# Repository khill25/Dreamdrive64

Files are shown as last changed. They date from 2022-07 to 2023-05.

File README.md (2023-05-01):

# DREAMDrive64
Nintendo 64 flash cart based around Raspberry Pi RP2040s. Load roms up to 64MB, EEPROM save support, supports all cic versions.

---
# Getting one
## Buy one from my website! 
https://dreamcraftindustries.com/products/dreamdrive64

## Build your own with PCBWay
You can load up the hw files in Kicad and use the PCBWay plugin. The PCBWay plugin will take you right to the PCBWay website with the gerbers loaded up and ready to order. 

### N64 Cartridge Shell
You can use a doner shell or find some on Aliexpress/Ebay.
The shell will need to be cut to accomodate the SD Card slot and USB port.

* SD Card Slot Cuts 
	* These cuts should be 15mm wide
		* This cut should start approximately 46.5mm from the bottom of the shell on the outside edge.
	* 3mm Deep on the back shell
	* Less than 1mm deep on the front shell
	
* "Boot" Button (Press while plugging in USB to load new firmware)
	* Drill small hole
		* 28.6mm from left side of back shell (5mm right of screw hole)
		* ~6.2mm down from the screw hole

---
# Current Dev Status
* DREAMDrive64 can boot roms and has made the v1.0.0 release! 
	* Menu rom can navigate the sd file system assuming a rational number of files/folders (256 at the moment per directory, 10 directory depth limit)
	* Menu rom can render thumbnail boxart of a rom when scrolling through file list
	* Libdragon changes are needed if you want to compile your own rom for the firmware, those changes are in PR over at the libdragon repo
	* Firmware is stable with a v1.0.0 release available right now, with more improvements on the way.

## Features
| Feature					| Status 	 | Notes 	|
|---:|:---|---:|
| Rom Loading				| Complete!	 |			|
| SD Filesystem navigation	| Complete!	 | Folder/File limit ~100 per directory 		|
| Wifi						| Soon		 |			|
| EEPROM save support		| Complete!		 |			|
| SRAM support 				| Complete!  | Some games require much higher sram timing than is currently working. SRAM doesn't save to SD card. SRAM data will only persist while the game is running.		|
| CIC Compatibility			| Complete!	 | All cic versions should work. Country version however needs to be matched with the version flashed to the board (PAL vs NTSC) |

**ROM Compatibility **
Still working towards booting at full sdk speeds (0x1240) but current v1.0.0 firmware is at 0x2040. SRAM access isn't fast enough for some titles. 

# Command Registers
| Register					| Address 	 | Length 	| Notes 				|
|---:|:---|:---|---:|
| Base Address				| 0x1FFE0000 | 0x1000	| 4kB buffer/Currently shared as internal buffer 			| v1/lite and v2|
| Command Interface Start	| 0x1FFE1000 | 0x0800	|						| 
| Random Seed 			| 0x1FFE0008 | 0x4		|						| 
| Start SD Read				| 0x1FFE000C | 0x4		|						| 
| SD Rom Select				| 0x1FFE0010 | 0x4		| Loads selected rom into psram	|
| SD Busy					| 0x1FFE0014 | 0x4  	| After an sd request is sent, data will be available at `Base Address` once sd busy = 0						| v2	|
| SD Read Sector Register 0	| 0x1FFE0018 | 0x4		| High bits of uint64 sector to read	|
| SD Read Sector Register 1	| 0x1FFE001C | 0x4		| Low bits of uin64 sector to read	|
| SD Read number of sectors	| 0x1FFE0020 | 0x4		| v2 code has this hard coded to always read 1 sector	|
| Select Rom				| 0x1FFE0024 | 0xFF		| Send title of rom to load from sd card e.g. "my_homebrew_rom.z64"	|

# Examples of SD card access
There is an open PR for sdfs support in the Libdragon repo! Check that out if you want to patch your libdragon installs.

Libdragon sdfs implementation for DreamDrive64. This code is just snippets and may not "just work" yet. It should give you an idea of how to use the command registers and the order that things need to be done in.
Example code to load a rom with the file's name. Updates to Libdragon's `debug.c` must be made if you plan on using file methods (e.g. f_open, f_read, etc...)
```
// From command register table above
// PC64_CIBASE_ADDRESS_START = "Command Interface start"
// PC64_REGISTER_SD_SELECT_ROM = "Select Rom"
void loadRomAtSelection(char* selectedFile) {
    char* fileToLoad = malloc(sizeof(char*) * 256);
    sprintf(fileToLoad, "%s", selectedFile);

    // Write the file name to the cart buffer
    uint32_t len_aligned32 = (strlen(fileToLoad) + 3) & (-4);
    data_cache_hit_writeback_invalidate(fileToLoad, len_aligned32);
    pi_write_raw(fileToLoad, PC64_BASE_ADDRESS_START, 0, len_aligned32);

    uint32_t sdSelectRomFilenameLength = strlen(fileToLoad);
    io_write(PC64_CIBASE_ADDRESS_START + PC64_REGISTER_SD_SELECT_ROM, sdSelectRomFilenameLength);

    wait_ms(100);
}
```

## Wait for SD
Taken from current (unmerged) libdragon implementation patch
```
static uint8_t pc64_sd_wait() {
    uint32_t timeout = 0;
    uint32_t isBusy __attribute__((aligned(8)));
	isBusy = 1;

    // Wait until the cartridge interface is ready
    do {
		
        // returns 1 while sd card is busy
		isBusy = io_read(PC64_CIBASE_ADDRESS_START + PC64_REGISTER_SD_BUSY);
        
        // Took too long, abort
        if((timeout++) > 10000000) {
			fprintf(stdout, "SD_WAIT timed out. isBusy: %ld\n", isBusy);
			return -1;
		}
    }
    while(isBusy != 0);
    (void) timeout; // Needed to stop unused variable warning

    // Success
    return 0;
}
```

## Read
Taken from current (unmerged) libdragon implementation patch
```
static DRESULT fat_disk_read_pc64(BYTE* buff, LBA_t sector, UINT count) {
	_Static_assert(FF_MIN_SS == 512, "this function assumes sector size == 512");
	_Static_assert(FF_MAX_SS == 512, "this function assumes sector size == 512");

	int retryCount = 2;
	int i = 0;
	do {
		uint64_t current_sector = sector + i;
		
		uint32_t part0 __attribute__((aligned(8)));
		part0 = (current_sector & 0xFFFFFFFF00000000LL) >> 32;

		uint32_t part1 __attribute__((aligned(8)));
		part1 = (current_sector & 0x00000000FFFFFFFFLL);

		// send sector
		io_write(PC64_CIBASE_ADDRESS_START + PC64_REGISTER_SD_READ_SECTOR0, part0);

		io_write(PC64_CIBASE_ADDRESS_START + PC64_REGISTER_SD_READ_SECTOR1, part1);

		// send num sectors to read
		io_write(PC64_CIBASE_ADDRESS_START + PC64_REGISTER_SD_READ_NUM_SECTORS, 1);

		// start the load
		io_write(PC64_CIBASE_ADDRESS_START + PC64_COMMAND_SD_READ, 1);

        // wait for the sd card to finish
        if(pc64_sd_wait() == 0) {
			data_cache_hit_writeback_invalidate(buff, 512);
			dma_read(buff, PC64_BASE_ADDRESS_START, 512);
			buff += 512;
			i++;
		} else {
			retryCount--;
			fprintf(stderr, "wait timeout\n");
		}

		if (retryCount <= 0) {
			break;
		}
		
	} while (i < count);

	return RES_OK;
}
```

## Write
Not supported yet!

# Join in on the fun!
Dreamcraft Industries discord

[Join the Dreamcraft Discord!](https://discord.gg/yawWMcv6tC)

Original PicoCart64 discord
Join the Discord server to participate in the discussion and development of this project.
[Dubious Technology Discord](https://discord.gg/2Gb3jWqqja)

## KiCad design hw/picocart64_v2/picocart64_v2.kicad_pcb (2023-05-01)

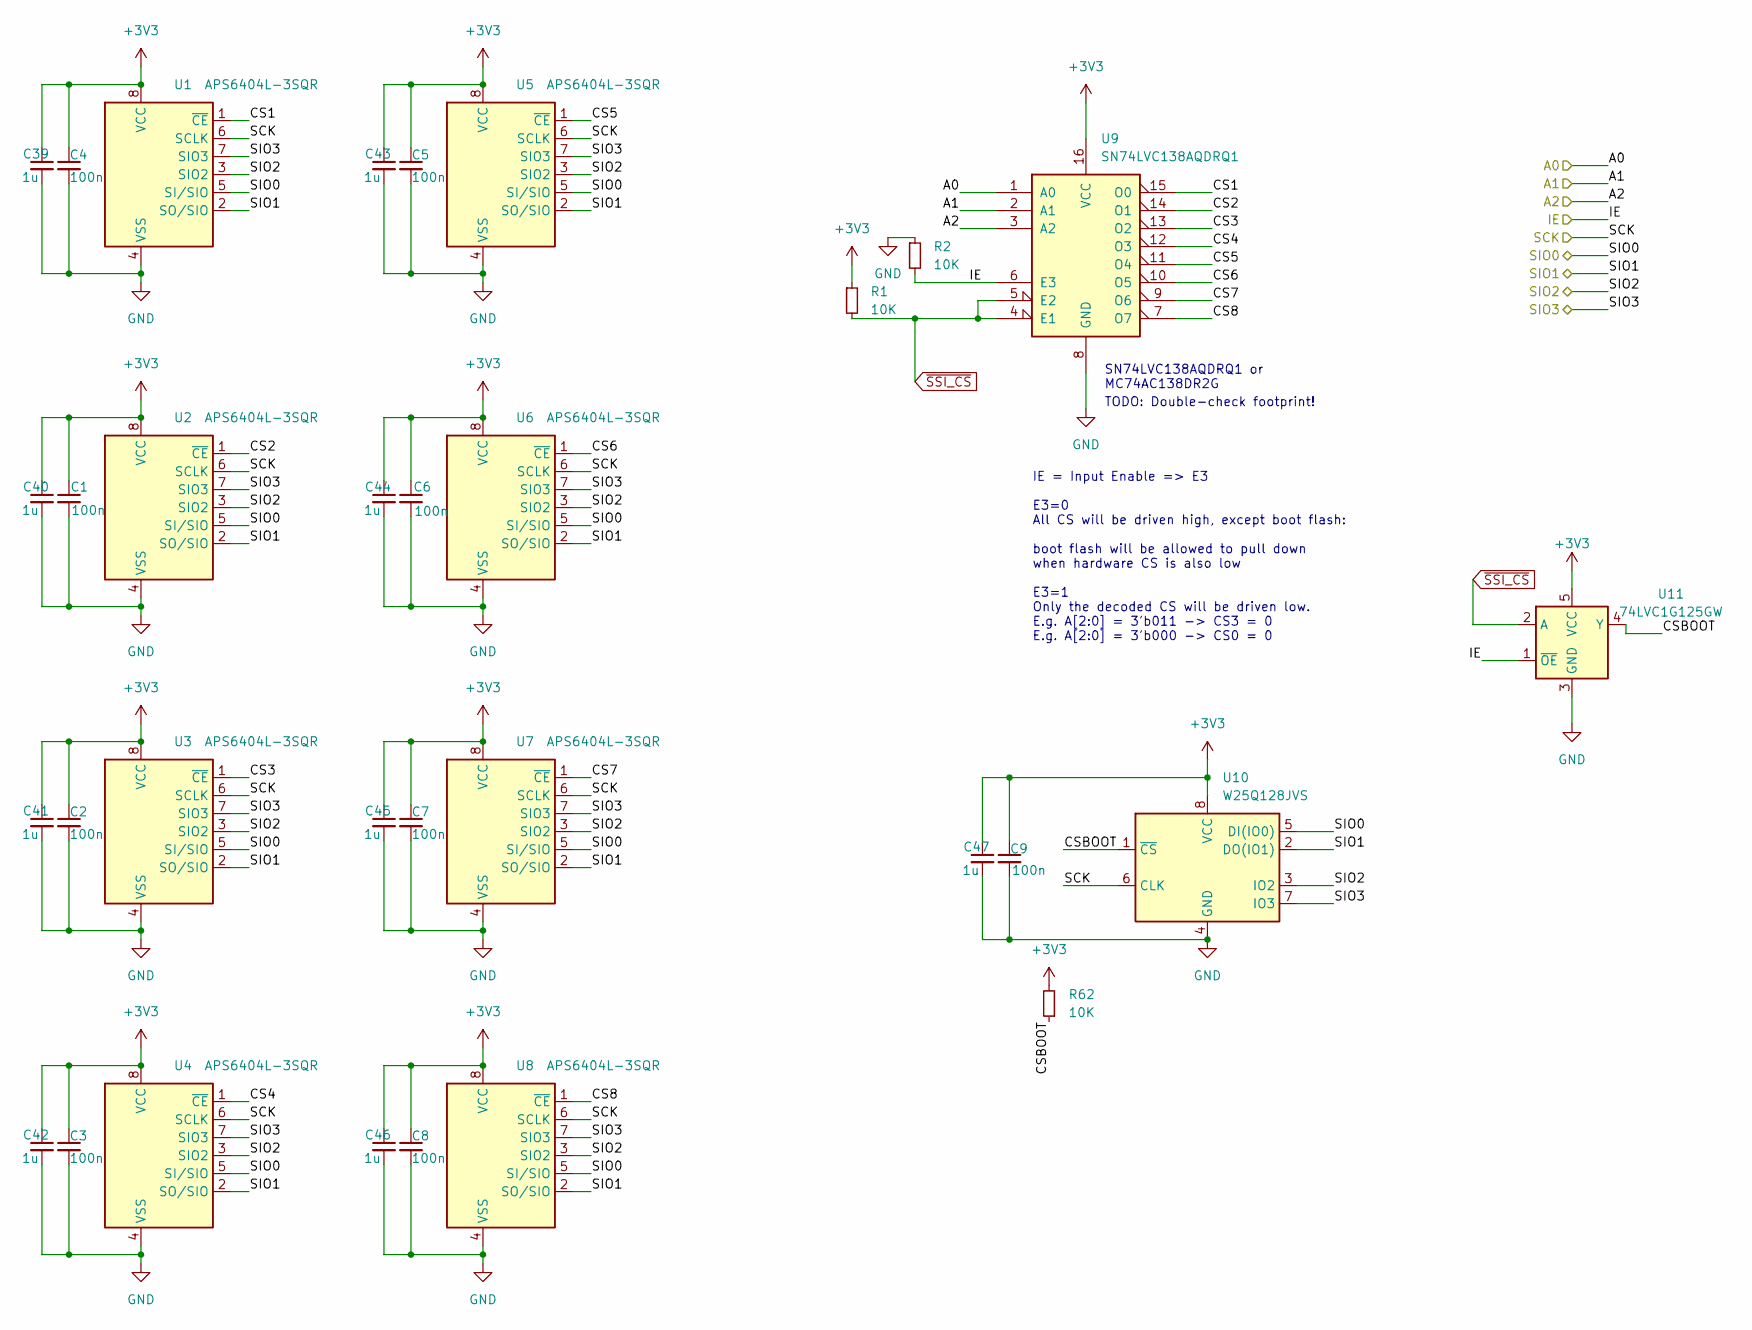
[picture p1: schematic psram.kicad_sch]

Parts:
C1, C2, C3, C4, C5, C6, C7, C8, C9: 100n; C_0402_1005Metric; LCSC C1525
C39, C40, C41, C42, C43, C44, C45, C46, C47: 1u; C_0402_1005Metric; LCSC C14445
R1, R2, R62: 10K; R_0402_1005Metric; LCSC C406733
U1, U2, U3, U4, U5, U6, U7, U8: APS6404L-3SQR; SOP-8_3.76x4.96mm_P1.27mm; LCSC Mouser: APS6404L-3SQR-SN
U9: SN74LVC138AQDRQ1; SOP-16_4.4x10.4mm_P1.27mm; LCSC C7816
U10: W25Q128JVS; SOIC-8_5.23x5.23mm_P1.27mm; LCSC C97521
U11: 74LVC1G125GW; SOT-353_SC-70-5; LCSC C12519

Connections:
+3V3: C1.1, C2.1, C3.1, C4.1, C5.1, C6.1, C7.1, C8.1, C9.1, C39.1, C40.1, C41.1, C42.1, C43.1, C44.1, C45.1, C46.1, C47.1, R1.1, R62.2, U1.8 (VCC), U2.8 (VCC), U3.8 (VCC), U4.8 (VCC), U5.8 (VCC), U6.8 (VCC), U7.8 (VCC), U8.8 (VCC), U9.16 (VCC), U10.8 (VCC), U11.5 (VCC); also elsewhere on the board
/Mainboard/DEMUX_A0: U9.1 (A0); also elsewhere on the board
/Mainboard/DEMUX_A1: U9.2 (A1); also elsewhere on the board
/Mainboard/DEMUX_A2: U9.3 (A2); also elsewhere on the board
/Mainboard/DEMUX_IE: R2.2, U9.6 (E3), U11.1 (~OE); also elsewhere on the board
/Mainboard/SSI_SCLK: U1.6 (SCLK), U2.6 (SCLK), U3.6 (SCLK), U4.6 (SCLK), U5.6 (SCLK), U6.6 (SCLK), U7.6 (SCLK), U8.6 (SCLK), U10.6 (CLK); also elsewhere on the board
/Mainboard/SSI_SD0: U1.5 (SI/SIO), U2.5 (SI/SIO), U3.5 (SI/SIO), U4.5 (SI/SIO), U5.5 (SI/SIO), U6.5 (SI/SIO), U7.5 (SI/SIO), U8.5 (SI/SIO), U10.5 (DI(IO0)); also elsewhere on the board
/Mainboard/SSI_SD1: U1.2 (SO/SIO), U2.2 (SO/SIO), U3.2 (SO/SIO), U4.2 (SO/SIO), U5.2 (SO/SIO), U6.2 (SO/SIO), U7.2 (SO/SIO), U8.2 (SO/SIO), U10.2 (DO(IO1)); also elsewhere on the board
/Mainboard/SSI_SD2: U1.3 (SIO2), U2.3 (SIO2), U3.3 (SIO2), U4.3 (SIO2), U5.3 (SIO2), U6.3 (SIO2), U7.3 (SIO2), U8.3 (SIO2), U10.3 (IO2); also elsewhere on the board
/Mainboard/SSI_SD3: U1.7 (SIO3), U2.7 (SIO3), U3.7 (SIO3), U4.7 (SIO3), U5.7 (SIO3), U6.7 (SIO3), U7.7 (SIO3), U8.7 (SIO3), U10.7 (IO3); also elsewhere on the board
/PSRAM Array/CS1: U1.1 (~CE), U9.15 (O0)
/PSRAM Array/CS2: U2.1 (~CE), U9.14 (O1)
/PSRAM Array/CS3: U3.1 (~CE), U9.13 (O2)
/PSRAM Array/CS4: U4.1 (~CE), U9.12 (O3)
/PSRAM Array/CS5: U5.1 (~CE), U9.11 (O4)
/PSRAM Array/CS6: U6.1 (~CE), U9.10 (O5)
/PSRAM Array/CS7: U7.1 (~CE), U9.9 (O6)
/PSRAM Array/CS8: U8.1 (~CE), U9.7 (O7)
/PSRAM Array/CSBOOT: R62.1, U10.1 (~CS), U11.4 (Y)
GND: C1.2, C2.2, C3.2, C4.2, C5.2, C6.2, C7.2, C8.2, C9.2, C39.2, C40.2, C41.2, C42.2, C43.2, C44.2, C45.2, C46.2, C47.2, R2.1, U1.4 (VSS), U2.4 (VSS), U3.4 (VSS), U4.4 (VSS), U5.4 (VSS), U6.4 (VSS), U7.4 (VSS), U8.4 (VSS), U9.8 (GND), U10.4 (GND), U11.3 (GND); also elsewhere on the board
~SSI_CS: R1.2, U9.4 (E1), U9.5 (E2), U11.2 (A); also elsewhere on the board

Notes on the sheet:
TODO: Double-check footprint!
IE = Input Enable => E3 E3=0 All CS will be driven high, except boot flash: boot flash will be allowed to pull down when hardware CS is also low E3=1 Only the decoded CS will be driven low. E.g. A[2:0] = 3'b011 -> CS3 = 0 E.g. A[2:0] = 3'b000 -> CS0 = 0
SN74LVC138AQDRQ1 or MC74AC138DR2G

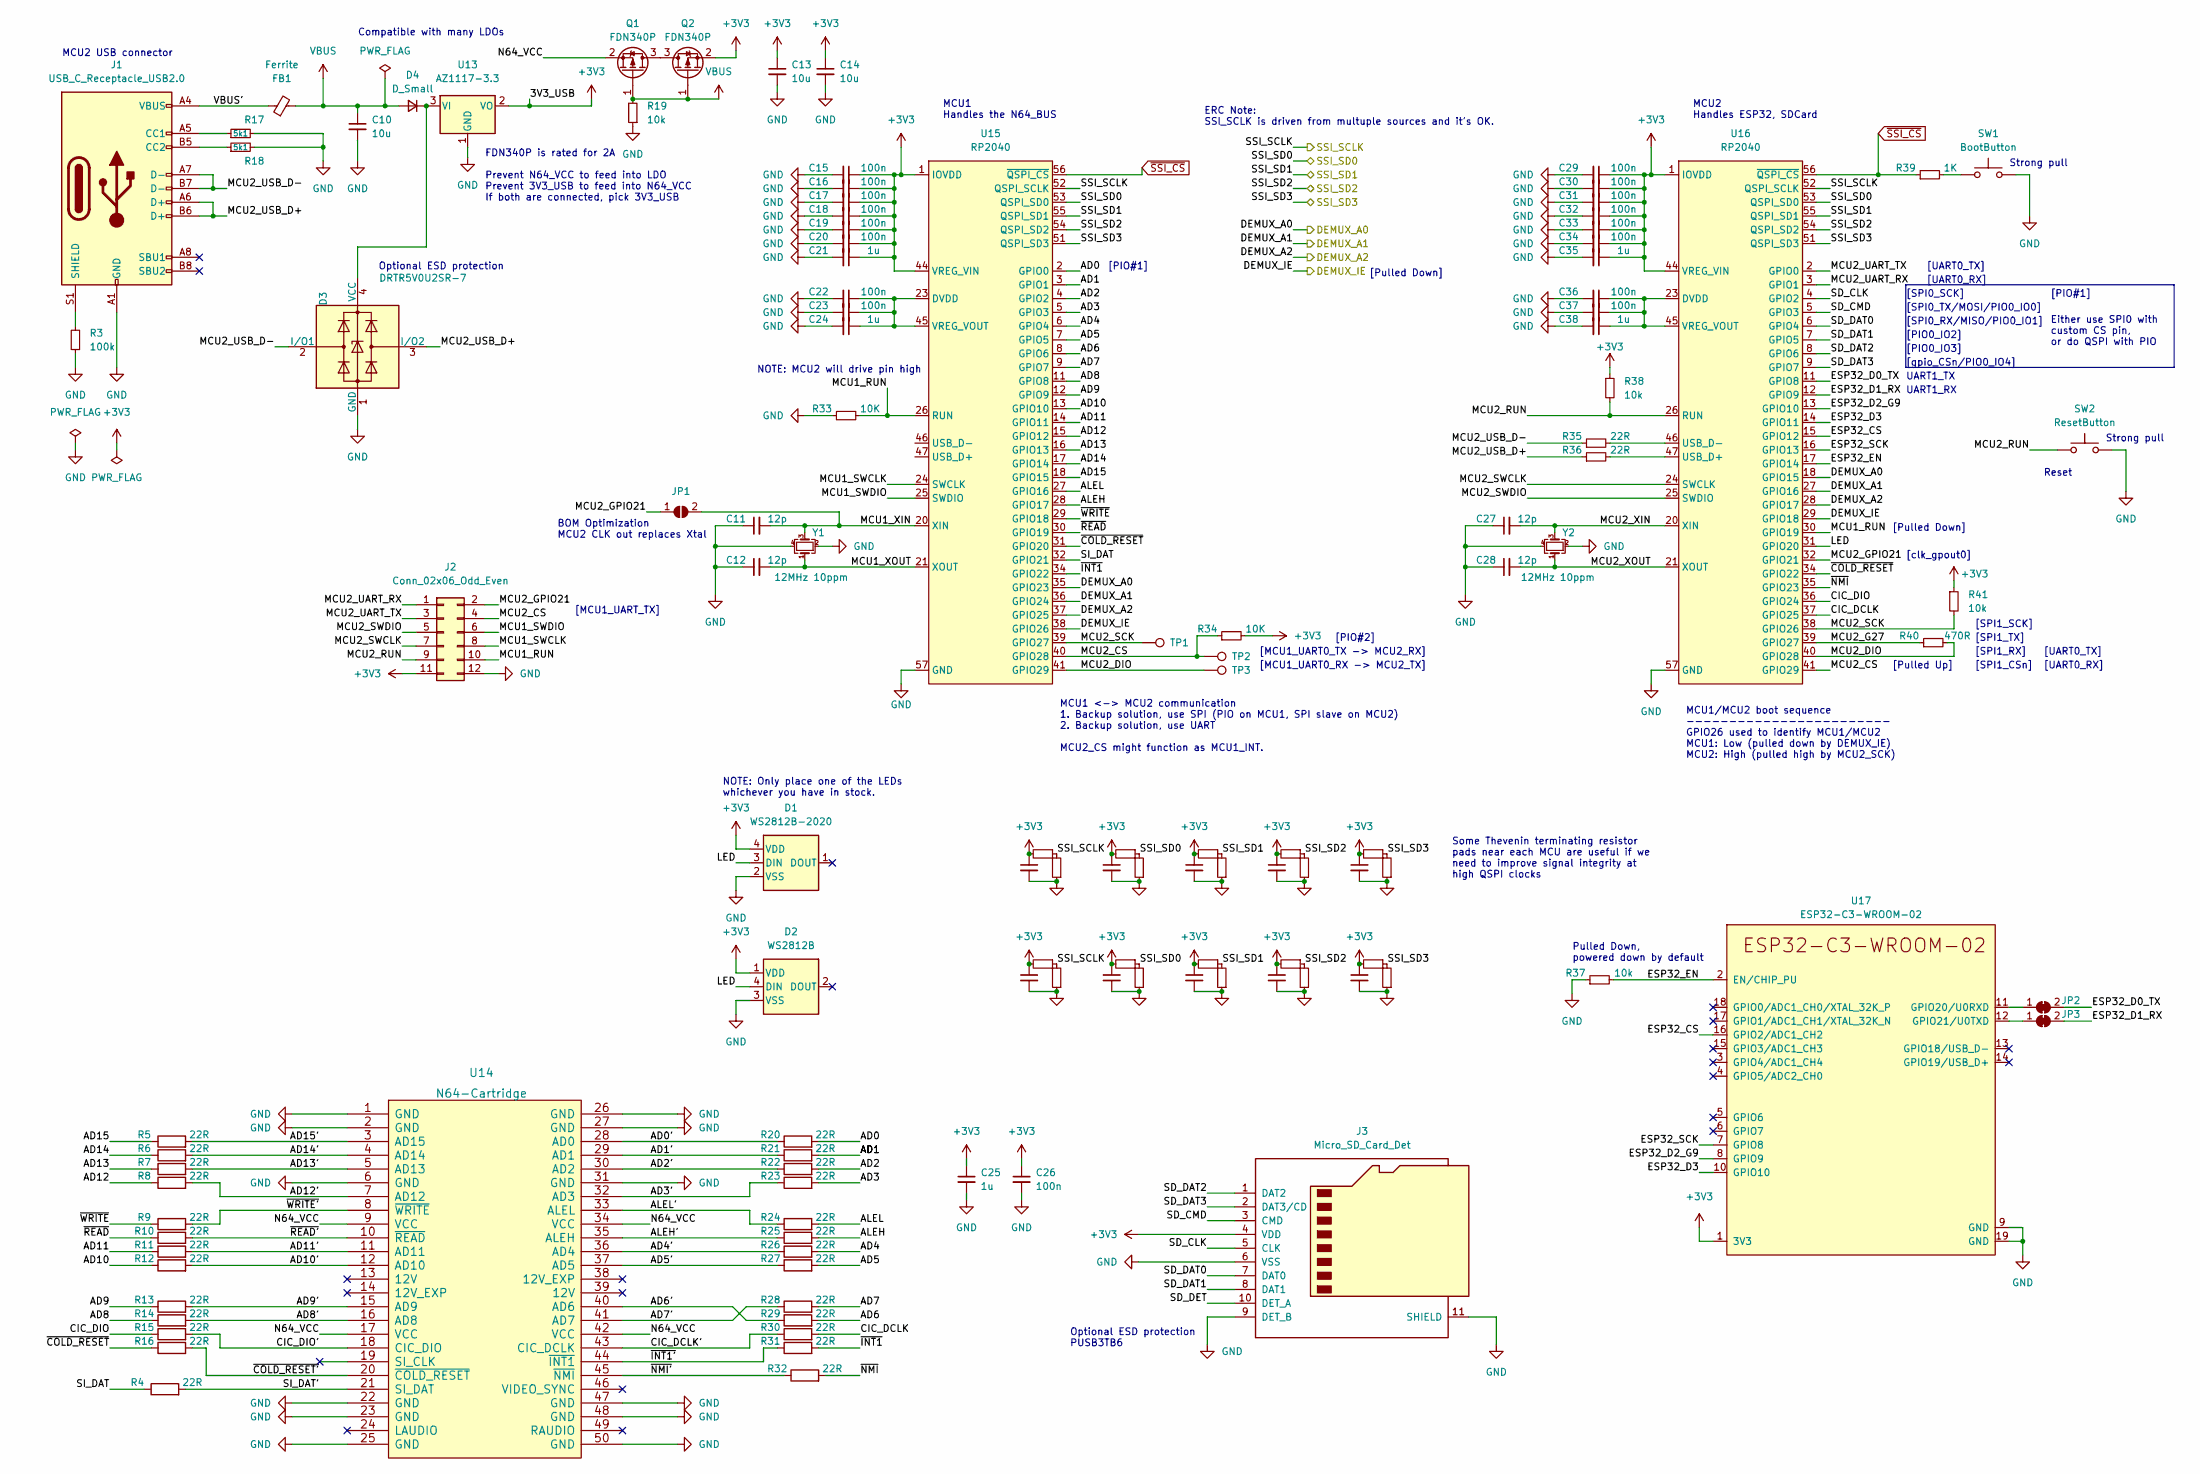
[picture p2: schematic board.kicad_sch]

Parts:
C10, C13, C14: 10u; C_0603_1608Metric; LCSC C15525
C11, C12, C27, C28: 12p; C_0402_1005Metric; LCSC C106201
C15, C16, C17, C18, C19, C20, C22, C23, C26, C29, C30, C31, C32, C33, C34, C36, C37, C48, C49, C50, C51, C52, C53, C54, C55, C56, C57: 100n; C_0402_1005Metric; LCSC C1525
C21, C24, C25, C35, C38: 1u; C_0402_1005Metric; LCSC C14445
D1: WS2812B-2020; LCSC C965555
D2: WS2812B; LED_WS2812B_PLCC4_5.0x5.0mm_P3.2mm; LCSC C114586
D3: DRTR5V0U2SR-7; SOT-143; LCSC C443828
D4: D_Small; D_SMA; LCSC C22452
FB1: Ferrite; L_0603_1608Metric; LCSC C76892
J1: USB_C_Receptacle_USB2.0; USB_C_Receptacle_GT-USB-7010; LCSC C136423
J2: Conn_02x06_Odd_Even; PinHeader_2x06_P2.54mm_Vertical_SMD
J3: Micro_SD_Card_Det; microSD_HC_Molex_104031-0811; LCSC C585350
JP1: SolderJumper_2_Open; SolderJumper-2_Small_Open
JP2, JP3: SolderJumper_2_Bridged; SolderJumper-2_Small_Closed
Q1, Q2: FDN340P; SOT-23; LCSC C347510
R3: 100k; R_0402_1005Metric; LCSC C25741
R4, R5, R6, R7, R8, R9, R10, R11, R12, R13, R14, R15, R16, R20, R21, R22, R23, R24, R25, R26, R27, R28, R29, R30, R31, R32, R35, R36: 22R; R_0402_1005Metric; LCSC C409710
R17, R18: 5k1; R_0402_1005Metric; LCSC C105873
R19, R37, R38, R41: 10k; R_0402_1005Metric; LCSC C406733
R33, R34: 10K; R_0402_1005Metric; LCSC C406733
R39, R42, R43, R44, R45, R46, R47, R48, R49, R50, R51, R52, R53, R54, R55, R56, R57, R58, R59, R60, R61: 1K; R_0402_1005Metric; LCSC C105637
R40: 470R; R_0402_1005Metric; LCSC C25117
SW1: BootButton; SW_SPST_FSMSM; LCSC C318938
SW2: ResetButton; SW_SPST_FSMSM; LCSC C318938
TP1: TP_MCU2_SCK; TestPoint_Pad_D1.0mm
TP2: TP_MCU2_CS; TestPoint_Pad_D1.0mm
TP3: TP_MCU2_DIO; TestPoint_Pad_D1.0mm
U13: AZ1117-3.3; SOT-223; LCSC C108495
U14: N64-Cartridge; N64-Connector
U15, U16: RP2040; QFN-56_EP_7x7_Pitch0.4mm; LCSC C2040
U17: ESP32-C3-WROOM-02; LCSC C2934560
Y1, Y2: 12MHz 10ppm; Crystal_SMD_2520-4Pin_2.5x2.0mm; LCSC C521567

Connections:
+3V3: C13.1, C14.1, C15.1, C16.1, C17.1, C18.1, C19.1, C20.1, C21.1, C25.1, C26.1, C29.1, C30.1, C31.1, C32.1, C33.1, C34.1, C35.1, C48.1, C49.1, C50.1, C51.1, C52.1, C53.1, C54.1, C55.1, C56.1, C57.1, D1.4 (VDD), D2.1 (VDD), J2.11, J3.4 (VDD), Q2.2 (S), R34.2, R38.1, R41.1, R42.2, R43.2, R46.2, R47.2, R50.2, R51.2, R54.2, R55.2, R58.2, R59.2, U13.2 (VO), U15.1 (IOVDD), U15.10 (IOVDD), U15.22 (IOVDD), U15.33 (IOVDD), U15.42 (IOVDD), U15.43 (ADC_AVDD), U15.44 (VREG_VIN), U15.48 (USB_VDD), U15.49 (IOVDD), U16.1 (IOVDD), U16.10 (IOVDD), U16.22 (IOVDD), U16.33 (IOVDD), U16.42 (IOVDD), U16.43 (ADC_AVDD), U16.44 (VREG_VIN), U16.48 (USB_VDD), U16.49 (IOVDD), U17.1 (3V3); also elsewhere on the board
/Mainboard/AD0: R20.2, U15.2 (GPIO0)
/Mainboard/AD0': R20.1, U14.28 (AD0)
/Mainboard/AD1: R21.2, U15.3 (GPIO1)
/Mainboard/AD1': R21.1, U14.29 (AD1)
/Mainboard/AD2: R22.2, U15.4 (GPIO2)
/Mainboard/AD2': R22.1, U14.30 (AD2)
/Mainboard/AD3: R23.2, U15.5 (GPIO3)
/Mainboard/AD3': R23.1, U14.32 (AD3)
/Mainboard/AD4: R26.2, U15.6 (GPIO4)
/Mainboard/AD4': R26.1, U14.36 (AD4)
/Mainboard/AD5: R27.2, U15.7 (GPIO5)
/Mainboard/AD5': R27.1, U14.37 (AD5)
/Mainboard/AD6: R29.2, U15.8 (GPIO6)
/Mainboard/AD6': R29.1, U14.40 (AD6)
/Mainboard/AD7: R28.2, U15.9 (GPIO7)
/Mainboard/AD7': R28.1, U14.41 (AD7)
/Mainboard/AD8: R14.1, U15.11 (GPIO8)
/Mainboard/AD8': R14.2, U14.16 (AD8)
/Mainboard/AD9: R13.1, U15.12 (GPIO9)
/Mainboard/AD9': R13.2, U14.15 (AD9)
/Mainboard/AD10: R12.1, U15.13 (GPIO10)
/Mainboard/AD10': R12.2, U14.12 (AD10)
/Mainboard/AD11: R11.1, U15.14 (GPIO11)
/Mainboard/AD11': R11.2, U14.11 (AD11)
/Mainboard/AD12: R8.1, U15.15 (GPIO12)
/Mainboard/AD12': R8.2, U14.7 (AD12)
/Mainboard/AD13: R7.1, U15.16 (GPIO13)
/Mainboard/AD13': R7.2, U14.5 (AD13)
/Mainboard/AD14: R6.1, U15.17 (GPIO14)
/Mainboard/AD14': R6.2, U14.4 (AD14)
/Mainboard/AD15: R5.1, U15.18 (GPIO15)
/Mainboard/AD15': R5.2, U14.3 (AD15)
/Mainboard/ALEH: R25.2, U15.28 (GPIO17)
/Mainboard/ALEH': R25.1, U14.35 (ALEH)
/Mainboard/ALEL: R24.2, U15.27 (GPIO16)
/Mainboard/ALEL': R24.1, U14.33 (ALEL)
/Mainboard/CIC_DCLK: R30.2, U16.37 (GPIO25)
/Mainboard/CIC_DCLK': R30.1, U14.43 (CIC_DCLK)
/Mainboard/CIC_DIO: R15.1, U16.36 (GPIO24)
/Mainboard/CIC_DIO': R15.2, U14.18 (CIC_DIO)
/Mainboard/DEMUX_A0: U15.35 (GPIO23), U16.18 (GPIO15); also elsewhere on the board
/Mainboard/DEMUX_A1: U15.36 (GPIO24), U16.27 (GPIO16); also elsewhere on the board
/Mainboard/DEMUX_A2: U15.37 (GPIO25), U16.28 (GPIO17); also elsewhere on the board
/Mainboard/DEMUX_IE: U15.38 (GPIO26), U16.29 (GPIO18); also elsewhere on the board
/Mainboard/ESP32_CS: U16.15 (GPIO12), U17.16 (GPIO2/ADC1_CH2)
/Mainboard/ESP32_D0_TX: JP2.2 (B), U16.11 (GPIO8)
/Mainboard/ESP32_D1_RX: JP3.2 (B), U16.12 (GPIO9)
/Mainboard/ESP32_D2_G9: U16.13 (GPIO10), U17.8 (GPIO9)
/Mainboard/ESP32_D3: U16.14 (GPIO11), U17.10 (GPIO10)
/Mainboard/ESP32_EN: R37.2, U16.17 (GPIO14), U17.2 (EN/CHIP_PU)
/Mainboard/ESP32_SCK: U16.16 (GPIO13), U17.7 (GPIO8)
/Mainboard/LED: D1.3 (DIN), D2.4 (DIN), U16.31 (GPIO20)
/Mainboard/MCU1_RUN: J2.10, R33.2, U15.26 (RUN), U16.30 (GPIO19)
/Mainboard/MCU1_SWCLK: J2.8, U15.24 (SWCLK)
/Mainboard/MCU1_SWDIO: J2.6, U15.25 (SWDIO)
/Mainboard/MCU1_XIN: C11.2, JP1.2 (B), U15.20 (XIN), Y1.3
/Mainboard/MCU1_XOUT: C12.2, U15.21 (XOUT), Y1.1
/Mainboard/MCU2_CS: J2.4, R34.1, TP2.1, U15.40 (GPIO28), U16.41 (GPIO29)
/Mainboard/MCU2_DIO: R40.2, TP3.1, U15.41 (GPIO29), U16.40 (GPIO28)
/Mainboard/MCU2_G27: R40.1, U16.39 (GPIO27)
/Mainboard/MCU2_GPIO21: J2.2, JP1.1 (A), U16.32 (GPIO21)
/Mainboard/MCU2_RUN: J2.9, R38.2, SW2.1, U16.26 (RUN)
/Mainboard/MCU2_SCK: R41.2, TP1.1, U15.39 (GPIO27), U16.38 (GPIO26)
/Mainboard/MCU2_SWCLK: J2.7, U16.24 (SWCLK)
/Mainboard/MCU2_SWDIO: J2.5, U16.25 (SWDIO)
/Mainboard/MCU2_UART_RX: J2.1, U16.3 (GPIO1)
/Mainboard/MCU2_UART_TX: J2.3, U16.2 (GPIO0)
/Mainboard/MCU2_USB_D+: D3.3 (I/O2), J1.A6 (D+), J1.B6 (D+), R36.1
/Mainboard/MCU2_USB_D-: D3.2 (I/O1), J1.A7 (D-), J1.B7 (D-), R35.1
/Mainboard/MCU2_XIN: C27.2, U16.20 (XIN), Y2.3
/Mainboard/MCU2_XOUT: C28.2, U16.21 (XOUT), Y2.1
/Mainboard/N64_VCC: Q1.2 (S), U14.9 (VCC), U14.17 (VCC), U14.34 (VCC), U14.42 (VCC)
/Mainboard/SD_CLK: J3.5 (CLK), U16.4 (GPIO2)
/Mainboard/SD_CMD: J3.3 (CMD), U16.5 (GPIO3)
/Mainboard/SD_DAT0: J3.7 (DAT0), U16.6 (GPIO4)
/Mainboard/SD_DAT1: J3.8 (DAT1), U16.7 (GPIO5)
/Mainboard/SD_DAT2: J3.1 (DAT2), U16.8 (GPIO6)
/Mainboard/SD_DAT3: J3.2 (DAT3/CD), U16.9 (GPIO7)
/Mainboard/SD_DET: J3.10 (DET_A)
/Mainboard/SI_DAT: R4.1, U15.32 (GPIO21)
/Mainboard/SI_DAT': R4.2, U14.21 (SI_DAT)
/Mainboard/SSI_SCLK: R42.1, R43.1, R44.2, R45.2, U15.52 (QSPI_SCLK), U16.52 (QSPI_SCLK); also elsewhere on the board
/Mainboard/SSI_SD0: R46.1, R47.1, R48.2, R49.2, U15.53 (QSPI_SD0), U16.53 (QSPI_SD0); also elsewhere on the board
/Mainboard/SSI_SD1: R50.1, R51.1, R52.2, R53.2, U15.55 (QSPI_SD1), U16.55 (QSPI_SD1); also elsewhere on the board
/Mainboard/SSI_SD2: R54.1, R55.1, R56.2, R57.2, U15.54 (QSPI_SD2), U16.54 (QSPI_SD2); also elsewhere on the board
/Mainboard/SSI_SD3: R58.1, R59.1, R60.2, R61.2, U15.51 (QSPI_SD3), U16.51 (QSPI_SD3); also elsewhere on the board
/Mainboard/VBUS': FB1.1, J1.A4 (VBUS), J1.A9 (VBUS), J1.B4 (VBUS), J1.B9 (VBUS)
/Mainboard/~COLD_RESET': R16.2, U14.20 (~COLD_RESET)
/Mainboard/~COLD_RESET: R16.1, U15.31 (GPIO20), U16.34 (GPIO22)
/Mainboard/~INT1': R31.1, U14.44 (~INT1)
/Mainboard/~INT1: R31.2, U15.34 (GPIO22)
/Mainboard/~NMI': R32.1, U14.45 (~NMI)
/Mainboard/~NMI: R32.2, U16.35 (GPIO23)
/Mainboard/~READ': R10.2, U14.10 (~READ)
/Mainboard/~READ: R10.1, U15.30 (GPIO19)
/Mainboard/~WRITE': R9.2, U14.8 (~WRITE)
/Mainboard/~WRITE: R9.1, U15.29 (GPIO18)
GND: C10.2, C11.1, C12.1, C13.2, C14.2, C15.2, C16.2, C17.2, C18.2, C19.2, C20.2, C21.2, C22.2, C23.2, C24.2, C25.2, C26.2, C27.1, C28.1, C29.2, C30.2, C31.2, C32.2, C33.2, C34.2, C35.2, C36.2, C37.2, C38.2, C48.2, C49.2, C50.2, C51.2, C52.2, C53.2, C54.2, C55.2, C56.2, C57.2, D1.2 (VSS), D2.3 (VSS), D3.1 (GND), J1.A1 (GND), J1.A12 (GND), J1.B1 (GND), J1.B12 (GND), J2.12, J3.6 (VSS), J3.9 (DET_B), J3.11 (SHIELD), R3.1, R17.2, R18.2, R19.1, R33.1, R37.1, R44.1, R45.1, R48.1, R49.1, R52.1, R53.1, R56.1, R57.1, R60.1, R61.1, SW1.2, SW2.2, U13.1 (GND), U14.1 (GND), U14.2 (GND), U14.6 (GND), U14.22 (GND), U14.23 (GND), U14.25 (GND), U14.26 (GND), U14.27 (GND), U14.31 (GND), U14.47 (GND), U14.48 (GND), U14.50 (GND), U15.19 (TESTEN), U15.57 (GND), U16.19 (TESTEN), U16.57 (GND), U17.9 (GND), U17.19 (GND), Y1.2, Y1.4, Y2.2, Y2.4; also elsewhere on the board
unnamed: C22.1, C23.1, C24.1, U15.23 (DVDD), U15.45 (VREG_VOUT), U15.50 (DVDD)
unnamed: C36.1, C37.1, C38.1, U16.23 (DVDD), U16.45 (VREG_VOUT), U16.50 (DVDD)
unnamed: D3.4 (VCC), D4.1 (K), U13.3 (VI)
unnamed: J1.A5 (CC1), R17.1
unnamed: J1.B5 (CC2), R18.1
unnamed: J1.S1 (SHIELD), R3.2
unnamed: JP2.1 (A), U17.11 (GPIO20/U0RXD)
unnamed: JP3.1 (A), U17.12 (GPIO21/U0TXD)
unnamed: Q1.3 (D), Q2.3 (D)
unnamed: R35.2, U16.46 (USB_D-)
unnamed: R36.2, U16.47 (USB_D+)
unnamed: R39.2, SW1.1
VBUS: C10.1, D4.2 (A), FB1.2, Q1.1 (G), Q2.1 (G), R19.2
~SSI_CS: R39.1, U15.56 (~QSPI_CS), U16.56 (~QSPI_CS); also elsewhere on the board

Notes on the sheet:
[UART0_TX]
[PIO0_IO2]
[Pulled Up]
[clk_gpout0]
UART1_TX
[MCU1_UART0_RX -> MCU2_TX]
NOTE: MCU2 will drive pin high
[Pulled Down]
Strong pull
[UART0_RX]
MCU2 Handles ESP32, SDCard
FDN340P is rated for 2A Prevent N64_VCC to feed into LDO Prevent 3V3_USB to feed into N64_VCC If both are connected, pick 3V3_USB
Optional ESD protection PUSB3TB6
NOTE: Only place one of the LEDs whichever you have in stock.
[PIO#1]
Compatible with many LDOs
UART1_RX
BOM Optimization MCU2 CLK out replaces Xtal
Some Thevenin terminating resistor pads near each MCU are useful if we need to improve signal integrity at high QSPI clocks
[SPI1_SCK]
[SPI0_TX/MOSI/PIO0_IO0]
MCU1/MCU2 boot sequence ------------------------ GPIO26 used to identify MCU1/MCU2 MCU1: Low (pulled down by DEMUX_IE) MCU2: High (pulled high by MCU2_SCK)
[SPI0_SCK]
Either use SPI0 with custom CS pin, or do QSPI with PIO
[MCU1_UART_TX]
[SPI1_TX]
[MCU1_UART0_TX -> MCU2_RX]
[SPI1_RX]
ERC Note: SSI_SCLK is driven from multuple sources and it's OK.
MCU2 USB connector
[PIO0_IO3]
[PIO#2]
Optional ESD protection
MCU1 <-> MCU2 communication 1. Backup solution, use SPI (PIO on MCU1, SPI slave on MCU2) 2. Backup solution, use UART MCU2_CS might function as MCU1_INT.
Reset
[SPI0_RX/MISO/PIO0_IO1]
Pulled Down, powered down by default
MCU1 Handles the N64_BUS
[gpio_CSn/PIO0_IO4]
[SPI1_CSn]

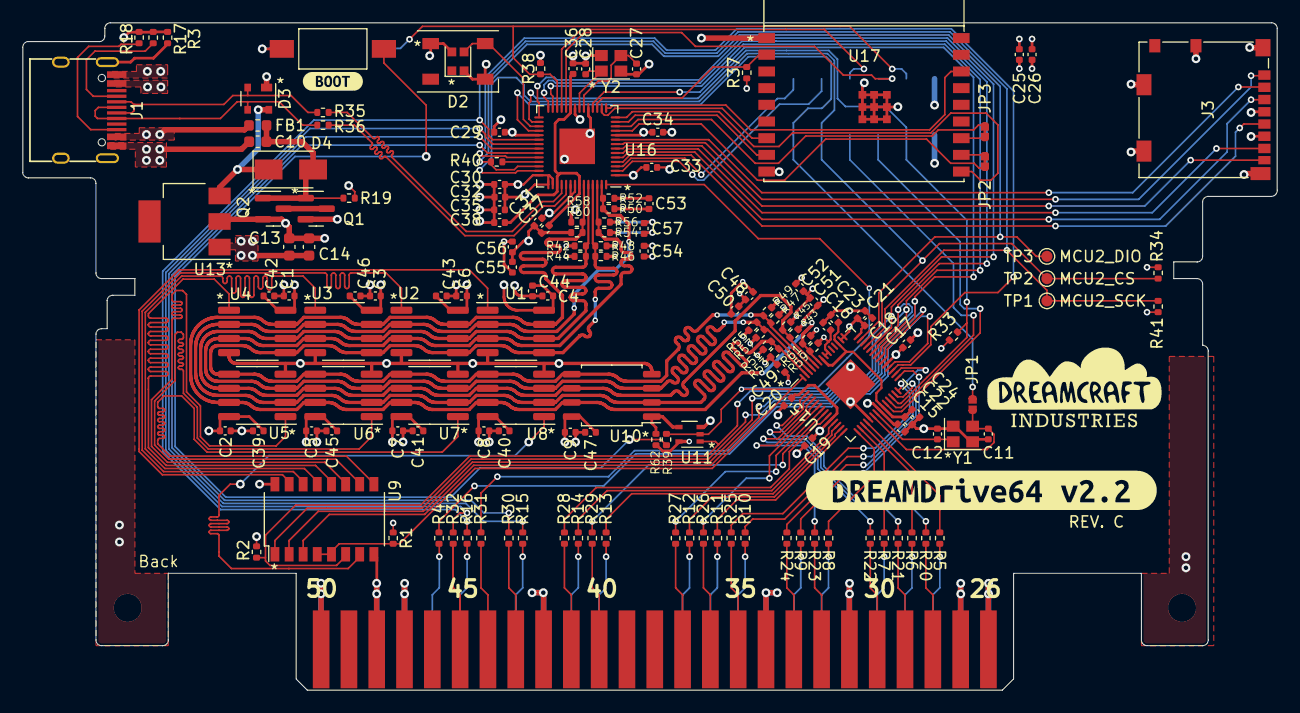
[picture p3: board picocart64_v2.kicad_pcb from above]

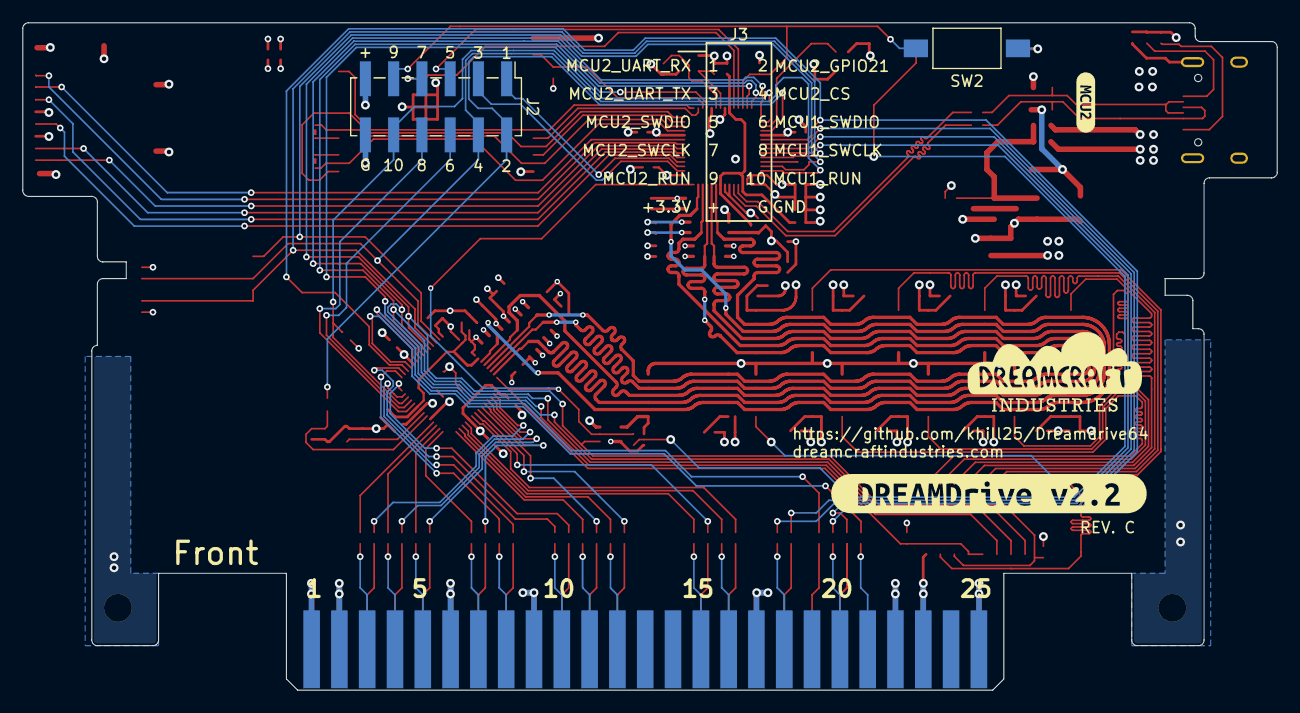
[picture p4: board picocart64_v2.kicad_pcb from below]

Board: 4 copper layers, 112.8 x 60.0 mm, 159 parts (5 on the bottom side), 121 nets.

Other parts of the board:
kibuzzard-62F8E97D: G***; kibuzzard-62F8E97D
kibuzzard-62F95F09: G***; kibuzzard-62F95F09
kibuzzard-63B14A32: G***; kibuzzard-63B14A32
kibuzzard-63B14B13: G***; kibuzzard-63B14B13

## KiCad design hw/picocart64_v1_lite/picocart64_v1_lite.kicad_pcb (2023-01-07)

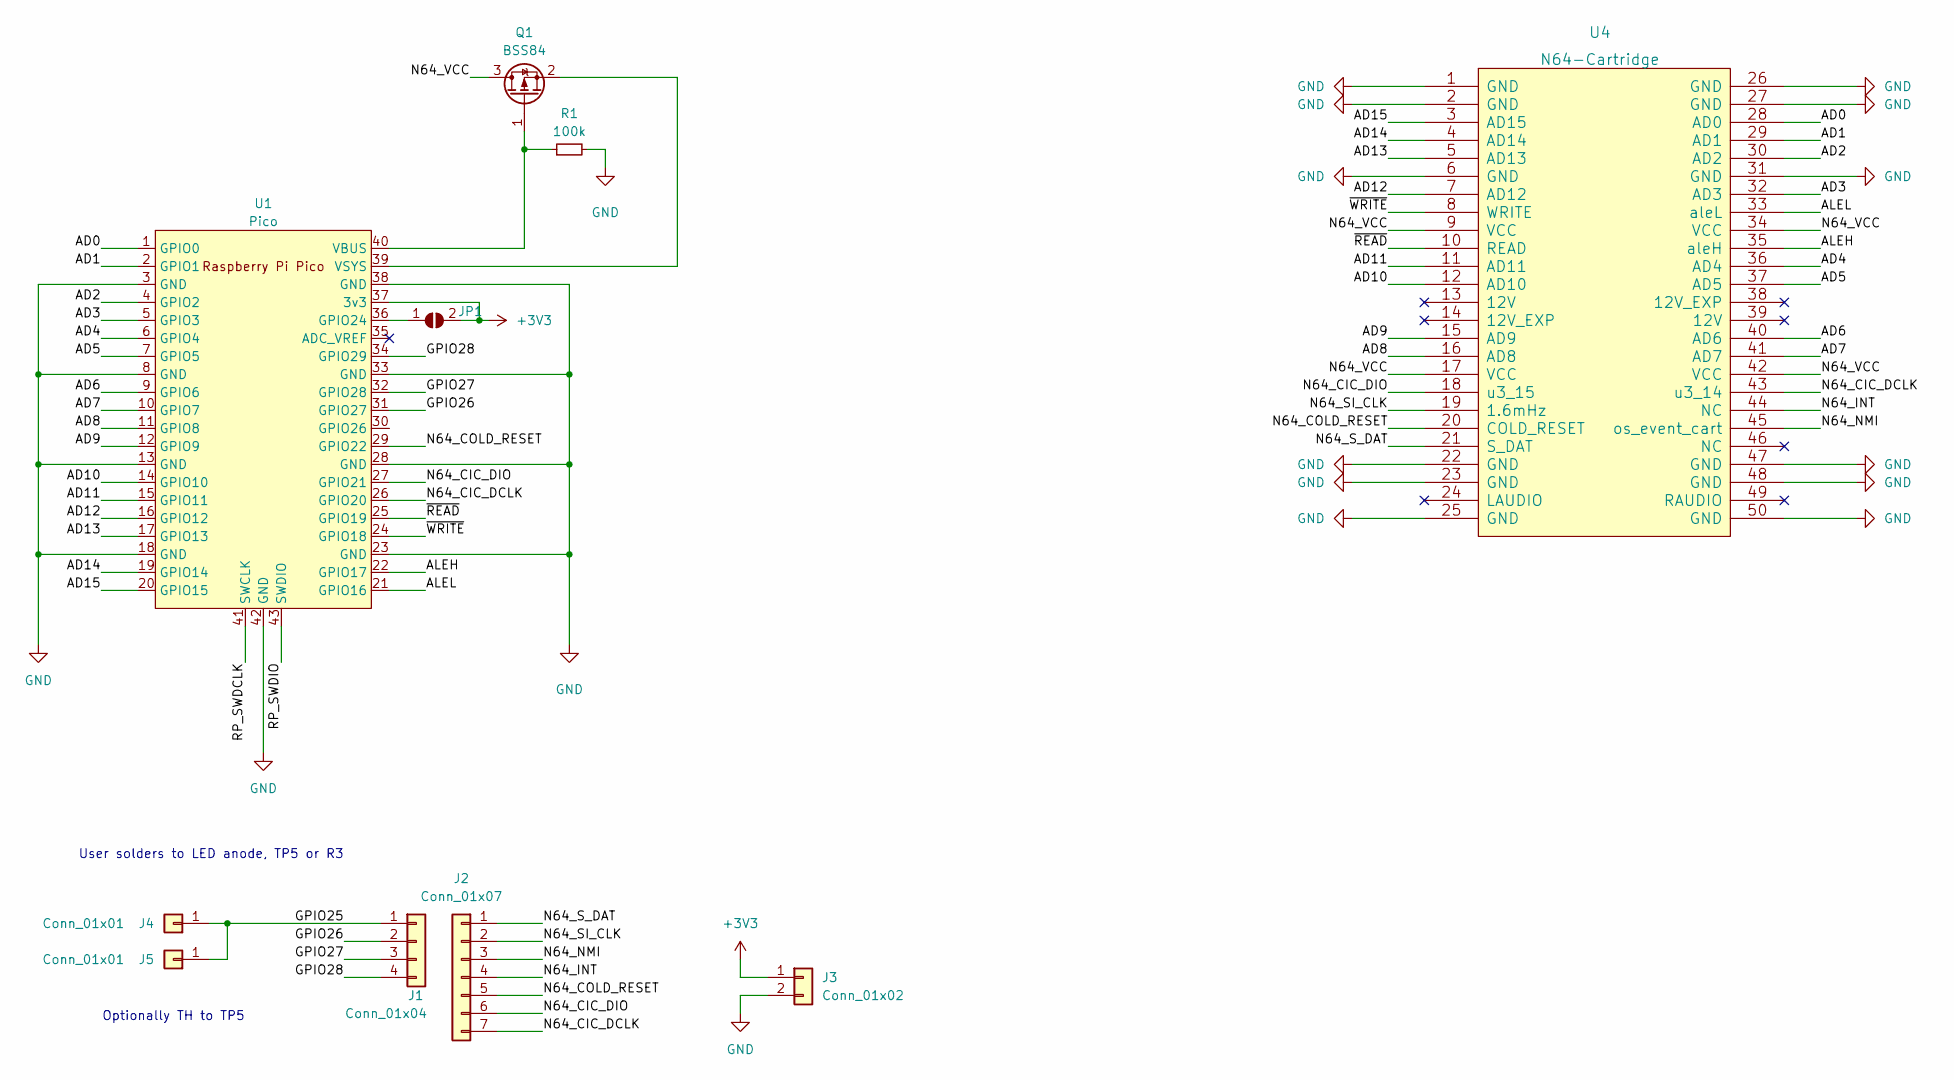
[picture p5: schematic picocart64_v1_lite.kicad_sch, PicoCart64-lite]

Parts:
J1: Conn_01x04; PinHeader_1x04_P2.54mm_Vertical
J2: Conn_01x07; PinHeader_1x07_P2.54mm_Vertical
J3: Conn_01x02; PinHeader_1x08_P2.54mm_Vertical
J4, J5: Conn_01x01; PinHeader_1x01_P2.54mm_Vertical
JP1: SolderJumper_2_Open; SolderJumper-2_P1.3mm_Open_RoundedPad1.0x1.5mm
Q1: BSS84; SOT-23
R1: 100k; R_0603_1608Metric_Pad0.98x0.95mm_HandSolder
U1: Pico; RPi_Pico_SMD_TH
U4: N64-Cartridge; N64-Connector

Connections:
+3V3: J3.1, JP1.2 (B), U1.37 (3v3)
/AD0: U1.1 (GPIO0), U4.28 (AD0)
/AD1: U1.2 (GPIO1), U4.29 (AD1)
/AD2: U1.4 (GPIO2), U4.30 (AD2)
/AD3: U1.5 (GPIO3), U4.32 (AD3)
/AD4: U1.6 (GPIO4), U4.36 (AD4)
/AD5: U1.7 (GPIO5), U4.37 (AD5)
/AD6: U1.9 (GPIO6), U4.40 (AD6)
/AD7: U1.10 (GPIO7), U4.41 (AD7)
/AD8: U1.11 (GPIO8), U4.16 (AD8)
/AD9: U1.12 (GPIO9), U4.15 (AD9)
/AD10: U1.14 (GPIO10), U4.12 (AD10)
/AD11: U1.15 (GPIO11), U4.11 (AD11)
/AD12: U1.16 (GPIO12), U4.7 (AD12)
/AD13: U1.17 (GPIO13), U4.5 (AD13)
/AD14: U1.19 (GPIO14), U4.4 (AD14)
/AD15: U1.20 (GPIO15), U4.3 (AD15)
/ALEH: U1.22 (GPIO17), U4.35 (aleH)
/ALEL: U1.21 (GPIO16), U4.33 (aleL)
/GPIO25: J1.1, J4.1, J5.1
/GPIO26: J1.2, U1.31 (GPIO27)
/GPIO27: J1.3, U1.32 (GPIO28)
/GPIO28: J1.4, U1.34 (GPIO29)
/N64_CIC_DCLK: J2.7, U1.26 (GPIO20), U4.43 (u3_14)
/N64_CIC_DIO: J2.6, U1.27 (GPIO21), U4.18 (u3_15)
/N64_COLD_RESET: J2.5, U1.29 (GPIO22), U4.20 (COLD_RESET)
/N64_INT: J2.4, U4.44 (NC)
/N64_NMI: J2.3, U4.45 (os_event_cart)
/N64_SI_CLK: J2.2, U4.19 (1.6mHz)
/N64_S_DAT: J2.1, U4.21 (S_DAT)
/N64_VCC: Q1.3 (D), U4.9 (VCC), U4.17 (VCC), U4.34 (VCC), U4.42 (VCC)
/RP_SWDCLK: U1.41 (SWCLK)
/RP_SWDIO: U1.43 (SWDIO)
/~READ: U1.25 (GPIO19), U4.10 (READ)
/~WRITE: U1.24 (GPIO18), U4.8 (WRITE)
GND: J3.2, R1.2, U1.3 (GND), U1.8 (GND), U1.13 (GND), U1.18 (GND), U1.23 (GND), U1.28 (GND), U1.33 (GND), U1.38 (GND), U1.42 (GND), U4.1 (GND), U4.2 (GND), U4.6 (GND), U4.22 (GND), U4.23 (GND), U4.25 (GND), U4.26 (GND), U4.27 (GND), U4.31 (GND), U4.47 (GND), U4.48 (GND), U4.50 (GND)
unnamed: Q1.1 (G), R1.1, U1.40 (VBUS)
unnamed: Q1.2 (S), U1.39 (VSYS)
unnamed: JP1.1 (A), U1.36 (GPIO24)

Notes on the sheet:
User solders to LED anode, TP5 or R3
Optionally TH to TP5

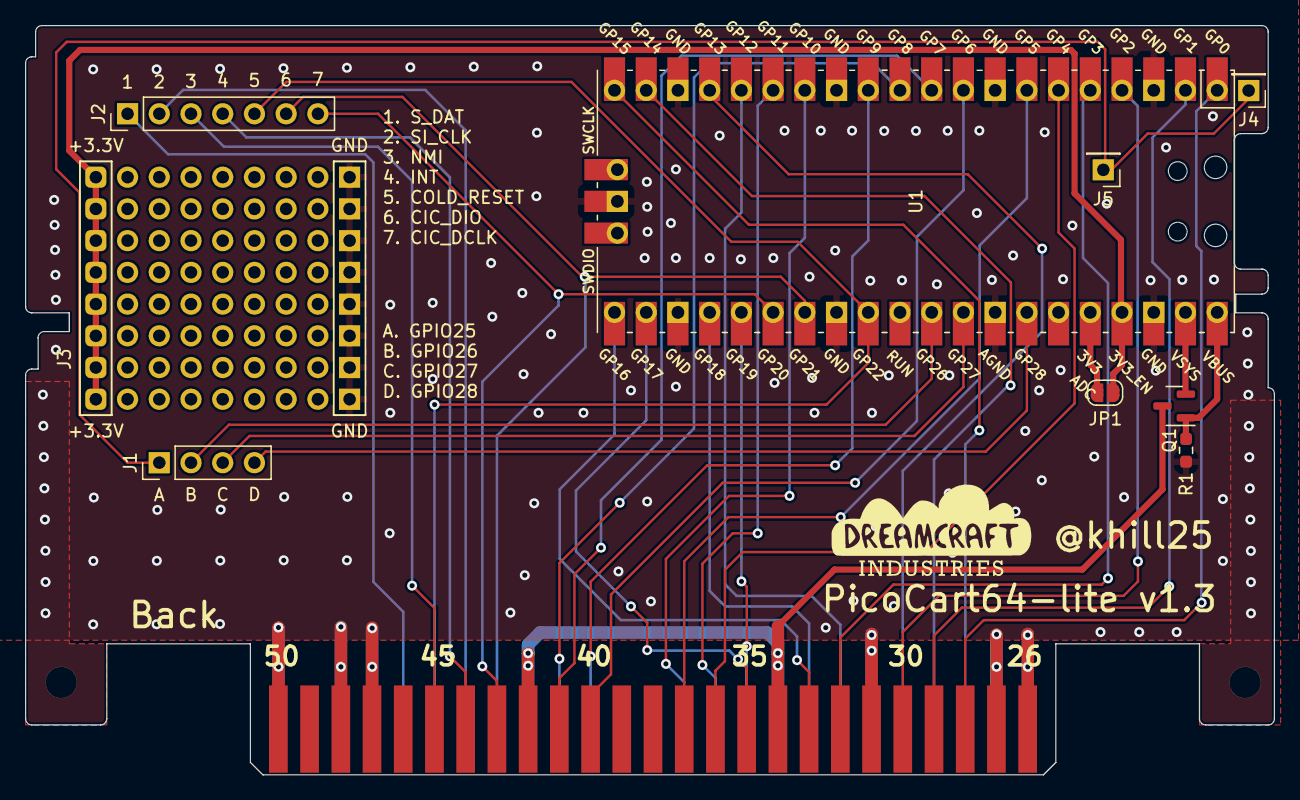
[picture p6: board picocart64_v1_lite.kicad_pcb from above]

Board: 2 copper layers, 100.0 x 60.0 mm, 10 parts (1 on the bottom side), 37 nets.

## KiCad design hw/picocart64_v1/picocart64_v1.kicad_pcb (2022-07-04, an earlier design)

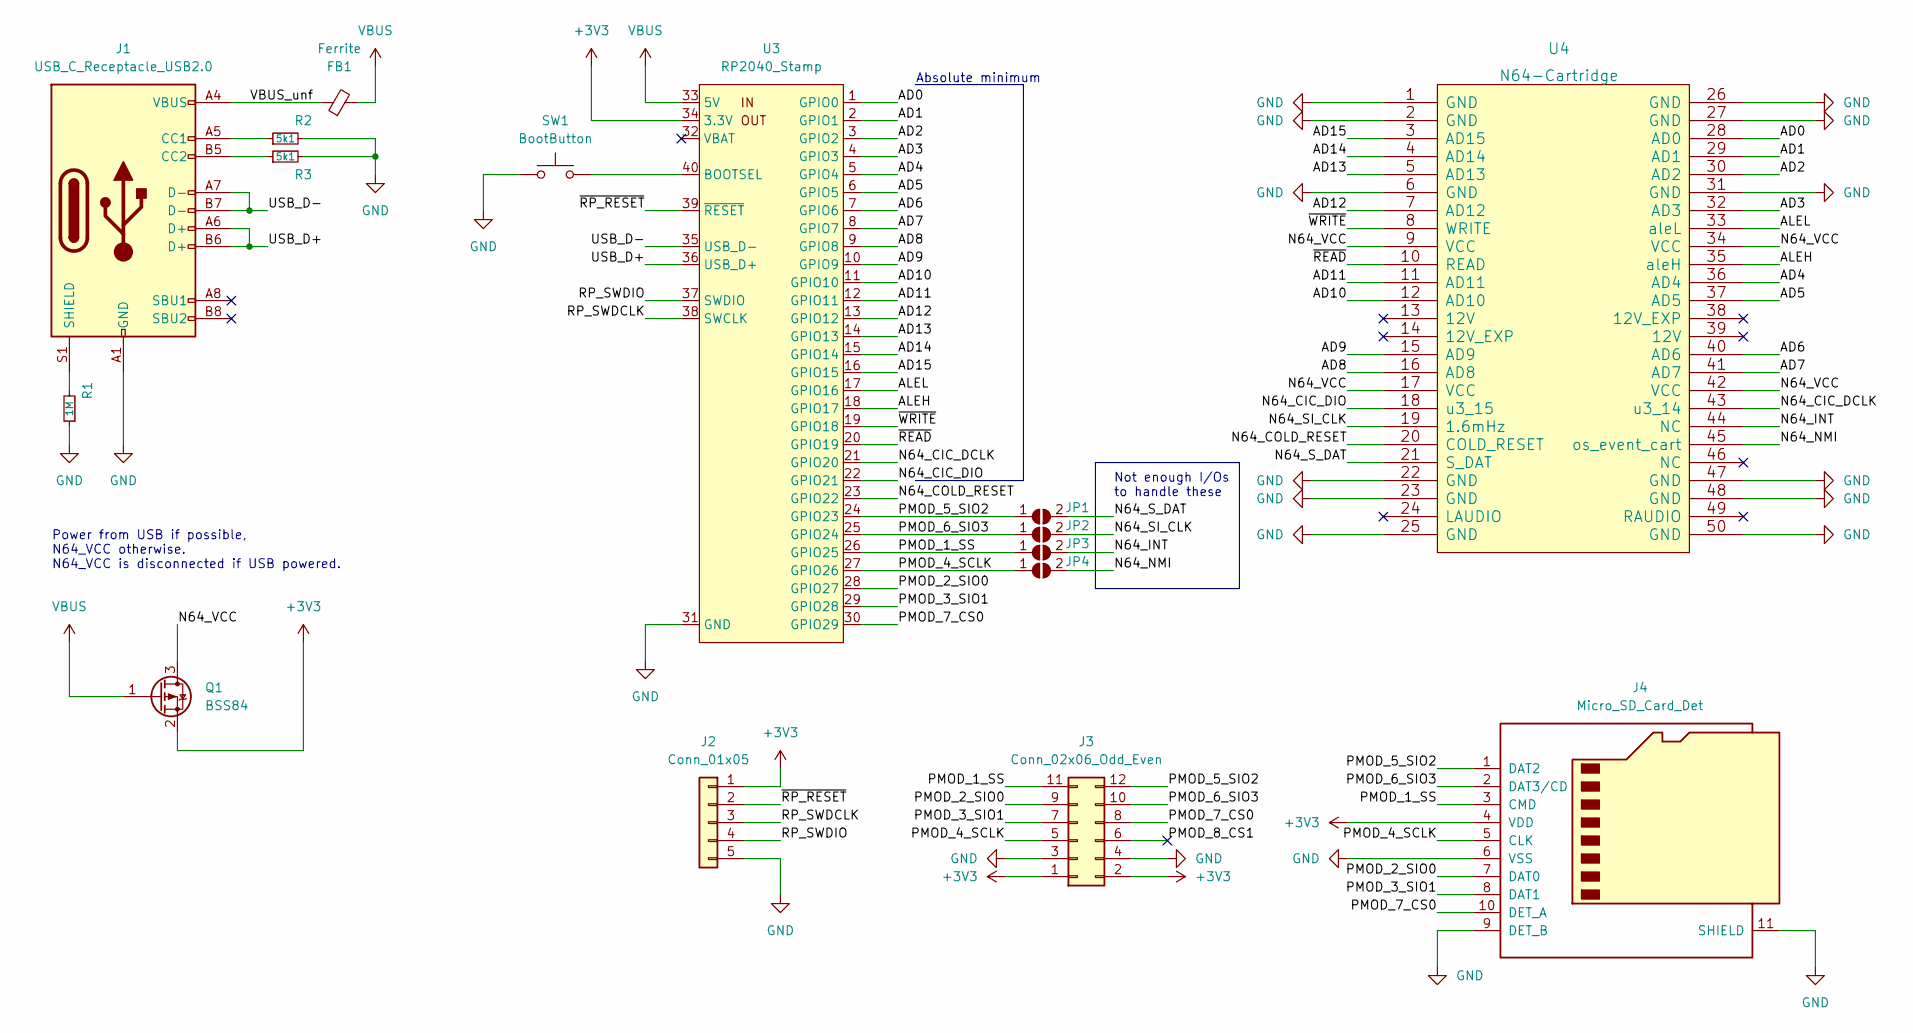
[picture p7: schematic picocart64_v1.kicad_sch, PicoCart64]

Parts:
FB1: Ferrite; L_0603_1608Metric
J1: USB_C_Receptacle_USB2.0; USB_C_Receptacle_GT-USB-7010
J2: Conn_01x05; PinHeader_1x05_P2.54mm_Vertical
J3: Conn_02x06_Odd_Even; PinSocket_2x06_P2.54mm_Horizontal
J4: Micro_SD_Card_Det; microSD_HC_Molex_104031-0811
JP1, JP2, JP3, JP4: SolderJumper_2_Open; SolderJumper-2_P1.3mm_Open_TrianglePad1.0x1.5mm
Q1: BSS84; SOT-23
R1: 1M; R_0603_1608Metric
R2, R3: 5k1; R_0603_1608Metric
SW1: BootButton; SW_SPST_FSMSM
U3: RP2040_Stamp; RP2040_Stamp_FlexyPin
U4: N64-Cartridge; N64-Connector

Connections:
+3V3: J2.1, J3.1, J3.2, J4.4 (VDD), Q1.2 (S), U3.34 (3.3V)
/AD0: U3.1 (GPIO0), U4.28 (AD0)
/AD1: U3.2 (GPIO1), U4.29 (AD1)
/AD2: U3.3 (GPIO2), U4.30 (AD2)
/AD3: U3.4 (GPIO3), U4.32 (AD3)
/AD4: U3.5 (GPIO4), U4.36 (AD4)
/AD5: U3.6 (GPIO5), U4.37 (AD5)
/AD6: U3.7 (GPIO6), U4.40 (AD6)
/AD7: U3.8 (GPIO7), U4.41 (AD7)
/AD8: U3.9 (GPIO8), U4.16 (AD8)
/AD9: U3.10 (GPIO9), U4.15 (AD9)
/AD10: U3.11 (GPIO10), U4.12 (AD10)
/AD11: U3.12 (GPIO11), U4.11 (AD11)
/AD12: U3.13 (GPIO12), U4.7 (AD12)
/AD13: U3.14 (GPIO13), U4.5 (AD13)
/AD14: U3.15 (GPIO14), U4.4 (AD14)
/AD15: U3.16 (GPIO15), U4.3 (AD15)
/ALEH: U3.18 (GPIO17), U4.35 (aleH)
/ALEL: U3.17 (GPIO16), U4.33 (aleL)
/N64_CIC_DCLK: U3.21 (GPIO20), U4.43 (u3_14)
/N64_CIC_DIO: U3.22 (GPIO21), U4.18 (u3_15)
/N64_COLD_RESET: U3.23 (GPIO22), U4.20 (COLD_RESET)
/N64_INT: JP3.2 (B), U4.44 (NC)
/N64_NMI: JP4.2 (B), U4.45 (os_event_cart)
/N64_SI_CLK: JP2.2 (B), U4.19 (1.6mHz)
/N64_S_DAT: JP1.2 (B), U4.21 (S_DAT)
/N64_VCC: Q1.3 (D), U4.9 (VCC), U4.17 (VCC), U4.34 (VCC), U4.42 (VCC)
/PMOD_1_SS: J3.11, J4.3 (CMD), JP3.1 (A), U3.26 (GPIO25)
/PMOD_2_SIO0: J3.9, J4.7 (DAT0), U3.28 (GPIO27)
/PMOD_3_SIO1: J3.7, J4.8 (DAT1), U3.29 (GPIO28)
/PMOD_4_SCLK: J3.5, J4.5 (CLK), JP4.1 (A), U3.27 (GPIO26)
/PMOD_5_SIO2: J3.12, J4.1 (DAT2), JP1.1 (A), U3.24 (GPIO23)
/PMOD_6_SIO3: J3.10, J4.2 (DAT3/CD), JP2.1 (A), U3.25 (GPIO24)
/PMOD_7_CS0: J3.8, J4.10 (DET_A), U3.30 (GPIO29)
/PMOD_8_CS1: J3.6
/RP_SWDCLK: J2.3, U3.38 (SWCLK)
/RP_SWDIO: J2.4, U3.37 (SWDIO)
/USB_D+: J1.A6 (D+), J1.B6 (D+), U3.36 (USB_D+)
/USB_D-: J1.A7 (D-), J1.B7 (D-), U3.35 (USB_D-)
/VBUS_unf: FB1.1, J1.A4 (VBUS), J1.A9 (VBUS), J1.B4 (VBUS), J1.B9 (VBUS)
/~READ: U3.20 (GPIO19), U4.10 (READ)
/~RP_RESET: J2.2, U3.39 (~RESET)
/~WRITE: U3.19 (GPIO18), U4.8 (WRITE)
GND: J1.A1 (GND), J1.A12 (GND), J1.B1 (GND), J1.B12 (GND), J2.5, J3.3, J3.4, J4.6 (VSS), J4.9 (DET_B), J4.11 (SHIELD), R1.1, R2.2, R3.2, SW1.1, U3.31 (GND), U4.1 (GND), U4.2 (GND), U4.6 (GND), U4.22 (GND), U4.23 (GND), U4.25 (GND), U4.26 (GND), U4.27 (GND), U4.31 (GND), U4.47 (GND), U4.48 (GND), U4.50 (GND)
unnamed: J1.A5 (CC1), R2.1
unnamed: J1.B5 (CC2), R3.1
unnamed: J1.S1 (SHIELD), R1.2
unnamed: SW1.2, U3.40 (BOOTSEL)
VBUS: FB1.2, Q1.1 (G), U3.33 (5V)

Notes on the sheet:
Power from USB if possible, N64_VCC otherwise. N64_VCC is disconnected if USB powered.
Not enough I/Os to handle these
Absolute minimum

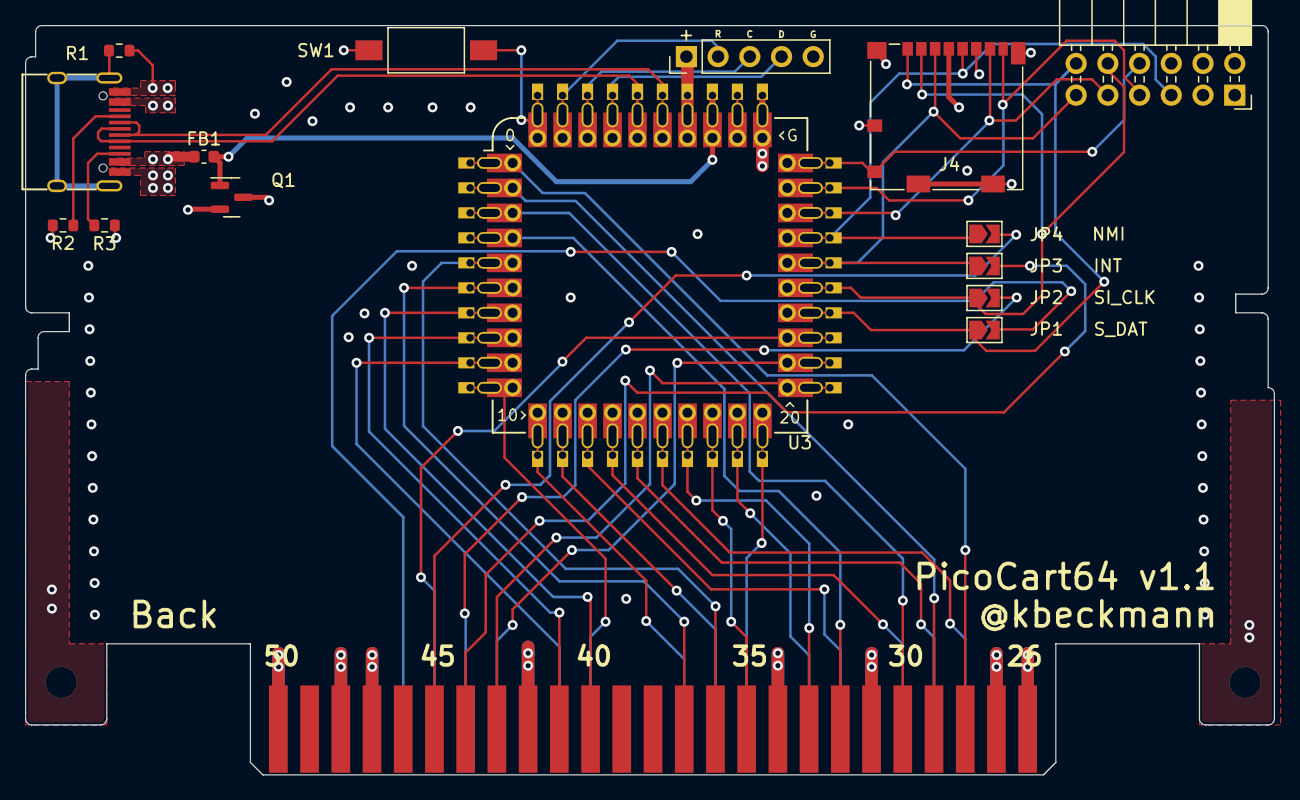
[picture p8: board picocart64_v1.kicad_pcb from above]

Board: 4 copper layers, 100.0 x 60.0 mm, 16 parts (1 on the bottom side), 48 nets.

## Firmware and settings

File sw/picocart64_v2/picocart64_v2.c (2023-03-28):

/**
 * SPDX-License-Identifier: BSD-2-Clause
 *
 * Copyright (c) 2022 Konrad Beckmann
 */

#include <stdio.h>

#include "pico/stdlib.h"
#include "hardware/structs/ssi.h"
#include "hardware/structs/ioqspi.h"
#include "hardware/vreg.h"

#include "FreeRTOS.h"
#include "task.h"

#include "mcu1.h"
#include "mcu2.h"
#include "qspi_helper.h"

#include "sdcard/internal_sd_card.h"

#define PIN_ID    (26)
#define MCU1_ID   ( 1)
#define MCU2_ID   ( 2)

bool g_isMCU1 = false;

/*
 * PicoCart64 v2 is connected in the following way:
 * MCU1        - FLASH (+PSRAM) - MCU2
 * MCU1.GPIO26                  - 10k Pull Down
 * MCU2.GPIO26                  - 10k Pull Up
 * MCU2.GPIO19 - MCU1.RUN       - 10k Pull Down
 *
 * MCU2 boots first, copies program from flash to RAM and executes.
 * MCU2 reads GPIO26. If HIGH: we are MCU2.
 * MCU2 sets QSPI OutputEnable override to Disabled.
 * MCU2 drives GPIO19 HIGH, letting MCU1 boot.
 * MCU1 boots, copies program from flash to RAM and executes.
 * MCU1 reads GPIO26. If LOW: we are MCU1.
 * MCU1 sets QSPI OutputEnable override to Disabled.
 * Done.
 *
 */

// FreeRTOS boilerplate
void vApplicationGetTimerTaskMemory(StaticTask_t ** ppxTimerTaskTCBBuffer, StackType_t ** ppxTimerTaskStackBuffer, uint32_t * pulTimerTaskStackSize)
{
	static StaticTask_t xTimerTaskTCB;
	static StackType_t uxTimerTaskStack[configTIMER_TASK_STACK_DEPTH];

	*ppxTimerTaskTCBBuffer = &xTimerTaskTCB;
	*ppxTimerTaskStackBuffer = uxTimerTaskStack;
	*pulTimerTaskStackSize = configTIMER_TASK_STACK_DEPTH;
}

int main(void)
{
	// const int freq_khz = 133000;
	// const int freq_khz = 133000;
	// const int freq_khz = 140000;
	// const int freq_khz = 160000;
	// const int freq_khz = 180000;
	// const int freq_khz = 200000;
	// const int freq_khz = 210000;
	// const int freq_khz = 220000;
	// const int freq_khz = 230000;
	// const int freq_khz = 240000;
	// const int freq_khz = 250000;
	const int freq_khz = 266000;

	// Frequencies above 266MHz require extra voltage, or at least did with all the units I tested
	// const int freq_khz = 300000; 
	// const int freq_khz = 300000; 
	// const int freq_khz = 336000; // Boots and runs games with a 4x qspi divider
	// const int freq_khz = 360000; // Boots and runs games (at stock sdk speeds!) with a 4x qspi divider
	// const int freq_khz = 380000; // Boots and may run games with a 4x qspi divider
	// const int freq_khz = 480000; // Does not boot?
	// vreg_set_voltage(VREG_VOLTAGE_1_25);
	// vreg_set_voltage(VREG_VOLTAGE_1_15);
	bool clockWasSet = set_sys_clock_khz(freq_khz, false);

	// On MCU1, PIN_ID is pulled low externally.
	// On MCU2, PIN_ID is pulled high externally and connected to MCU1.RUN.
	gpio_init(PIN_ID);
	gpio_set_dir(PIN_ID, GPIO_IN);
	gpio_disable_pulls(PIN_ID);

	// mcu_id will be 1 for MCU1, and 2 for MCU2.
	int mcu_id = gpio_get(PIN_ID) + 1;
	PC64_MCU_ID = mcu_id;

	if (mcu_id == MCU1_ID) {
		g_isMCU1 = true;

		mcu1_main();
	} else if (mcu_id == MCU2_ID) {
		g_isMCU1 = false;

		// Turn off SSI
		ssi_hw->ssienr = 0;
		// Disable output enable (OE) on all QSPI IO pins
		qspi_oeover_disable();
		
		// It's up to MCU2 to let MCU1 boot 
		mcu2_main();
	}
	// Never reached
	while (true) {
	}

	return 0;
}

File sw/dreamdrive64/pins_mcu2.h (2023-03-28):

/**
 * SPDX-License-Identifier: BSD-2-Clause
 *
 * Copyright (c) 2022 Konrad Beckmann
 */

#pragma once

#define PIN_UART0_TX          ( 0)
#define PIN_UART0_RX          ( 1)
#define PIN_SD_CLK            ( 2)
#define PIN_SD_CMD            ( 3)
#define PIN_SD_DAT0_UART1_TX  ( 4)
#define PIN_SD_DAT1_UART1_RX  ( 5)
#define PIN_SD_DAT2           ( 6)
#define PIN_SD_DAT3           ( 7)
#define PIN_ESP32_D0          ( 8)
#define PIN_ESP32_D1          ( 9)
#define PIN_ESP32_D2          (10)
#define PIN_ESP32_D3          (11)
#define PIN_ESP32_CS          (12)
#define PIN_ESP32_SCK         (13)
#define PIN_ESP32_EN          (14)
#define PIN_DEMUX_A0          (15)
#define PIN_DEMUX_A1          (16)
#define PIN_DEMUX_A2          (17)
#define PIN_DEMUX_IE          (18)
#define PIN_MCU1_RUN          (19)
#define PIN_LED               (20)
#define PIN_MCU2_GPIO21       (21)
#define PIN_N64_COLD_RESET    (22)
#define PIN_N64_NMI           (23)
#define PIN_CIC_DIO           (24)
#define PIN_CIC_DCLK          (25)
#define PIN_SPI1_SCK          (26)
#define PIN_SPI1_TX           (27)
#define PIN_SPI1_RX           (28)
#define PIN_SPI1_CS           (29)

#define PIO_UART_BAUD_RATE 115200

#define DEBUG_UART uart0
#define DEBUG_UART_BAUD_RATE 115200
#define DEBUG_UART_TX_PIN (PIN_UART0_TX)
#define DEBUG_UART_RX_PIN (PIN_UART0_RX)

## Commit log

2022-07-04 WIP utils that mimic the n64 (run on a second pico) to verify data that a pico running PicoCart64 is sending expected data. Should be useful to measure latency and other testing related question.
2022-07-06 Commented out a bunch of n64 data tester code while I'm debugging an issue with the PIO program (I think it might be solved but pivoted to testing flash memory) Added a new test build config that can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
2022-08-01 Work to add sd card reading to pico and rom
2022-08-11 Sanity commit. Moved a bunch of code around. Commented out some unused (in picocart) code. Added 4 registers for the sd card sector that is to be read as it's a 64 bit value. Currently investigating 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
2022-09-21 Comment out sleeps in v2 code that cause crash when debugging. Update CmakeList to use 'Debug' so the debugger/picoprobe will work correctly.
    [mcu2.c]
2022-09-25 Output stdio to uart
2022-11-08 SPI instead of UART. Still debugging.
2022-11-08 Debug jank everywhere. Leave the input synchronizer on, on the slave. Make the slave much faster (in this case 8x faster than master)
2022-11-09 A little clean up Increase uart speed in hopes of fixing any printf bottlenecks. Decreased the master pio spi speed. Changed 64bit variable to 32 bit as there was some weird compiler issue that was s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
    [internal_sd_card.c, mcu1.c, mcu2.c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]
2022-11-10 A little cleanup. More flailing trying to get pio spi to write into the array.
2022-11-10 Revert number of bits to pull from pio back to 8 from 32.
    [pio_spi.c]
2023-01-06 Updated ff sdio implementation but it's slower than spi and not sure it's even returning the right data.
2023-01-07 Changes to v1 lite board to allow drop in weact as default instead of pico.
    [picocart64_v1_lite.kicad_pcb, picocart64_v1_lite.kicad_sch]
2023-01-19 Changed the cic file to allow switching the cic chip a little easier.
2023-01-20 Nothing to do with libretro integration: Working on getting roms booting at full speed on v2. Fixed v1 as the cic changed.
    [mcu1.c, mcu2.c, n64_pi_task.c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]
2023-01-21 New v2 board revision (v2.2) updated with help from Snipeye. Updated readme.
    [board.kicad_sch, picocart64_v2.kicad_pcb, picocart64_v2.kicad_sch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]
2023-01-21 Pulled in some libretro files and made a few modifications to get everything compiling. Won't build binary due the fact that it overflows 8kbytes. Trimming will be needed.
    [mcu2.c]
2023-01-21 Working implementation to read libretro-db. It's slow. Query is hard coded to look for goldeneye by serial. Speed is likely limited by the spi access to the sd card
2023-01-23 Update readme Clean up pc64 reg header file Add some notes to mcu1/2 about processor clk speeds. Removed some unused code in internal_sd_card and added a pragma to disable debug printing if desired.
2023-01-24 v1/lite Boot at full speed. Also had to adjust my boot.h file in my pico-sdk since I'm still hand editing that to change flash divider and startup delay for v2 boards
2023-01-28 Experimenting with dma value fetching and using the whole returned 32bit value.
2023-01-29 Check in before trying new approach with dma.
2023-01-29 Dual dma channel approach doesn't really appear to work. Boots kinda, will show logo if patched to slowest speed.
    [internal_sd_card.c, mcu1.c, mcu2.c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]
2023-01-29 Went back to single dma channel and slower patched speed. Rom boots shows the initial screen but then black screens.
2023-01-29 Small refactor to move the dma rom fetching code back into it's method. Do the same for the test code. Still not booting past the initial screen on goldeney
2023-01-29 Just for sanity, went back to pointer method (and have to remember to swap8 the data) and that IS loading the game
    [mcu1.c, n64_pi_task.c]
2023-01-30 Try not starting the read in the set_write_addr and use dma_channel_start instead. This doesn't fix the problem.
    [n64_pi_task.c]
2023-02-16 Updated v2 pcb to use a tristate buffer to toggle between boot flash and psram array.
    [board.kicad_sch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]
2023-02-28 Went back to using "stock" spi config for the sd card. Changed back to 6102 cic for goldeneye while debugging new boards. Still isn't booting? Want to make sure something funny isn't happening.
2023-03-03 Wrote a test that will read data on mcu1 and send it to mcu2 for verification.
    Still trying to narrow down the issue with the dataline reflections. Tried terminating resistors on the data legs and clk pin but it didn't seem to fix any of the issues to mcu1. MCU2 WAS able to read at 133mhz with some 330ohm resistors on u4 and u8 and a drive strength of 8mA
    [internal_sd_card.c, mcu1.c, mcu2.c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]
2023-03-03 Updated schematic to use correct footprints for the psram. Also updated the components and datasheets for the tristate buffer and psram.
    [picocart64_v2.kicad_pcb, picocart64_v2.kicad_sch, psram.kicad_sch]
2023-03-07 Huge clean up. Moved and renamed functions from program_flash_array into qspi_helper. Removed a bunch of used code. n64_pi handler will now correctly launch the menu rom and switch when a rom is load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
    [internal_sd_card.c, joybus.c, mcu1.c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]
2023-03-07 Hacked pio uart to run about 6-8x faster. Seems to be stable.
2023-03-08 Added in a missing break statement in mcu1's main loop as it was falling through the switch on accident. Lowered the pio_uart clk divider from 4->8 as there were errors while sending sd card data. St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
    [internal_sd_card.c, mcu1.c, mcu2.c]
2023-03-08 Created my own A and B button icons for the menu rom. Updated colors. Added scrolling text to long names in list. TODO for the info panel. Went back to "slow" inter-mcu uart as the "fast" changes cau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
2023-03-09 Updated fatfs for the SDIO changes. Read speeds are much higher on the sd card now. Made changes to fatfs library (changed pio divider to account for overclocked rp2040) and also to change hard coded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
2023-03-13 IMPORTANT:: pick-sdk crt0.S was modified to speed up rp2040 boot time. _reset_handler: ldr r0, =(ROSC_BASE + ROSC_DIV_OFFSET) ldr r1, =0xaa1 str r1, [r0]
    Overclock rp2040s to 360MHz (they get warm but seem to be okay)
    Allows full speed rom booting.
    Moved some files in the menu rom so they don't compile into the rom and bloat the size.
    Added in gameCic to menu rom so when it loads a new game it can properly set the cic of the rom being loaded.
    TODO this needs to be setup so it will properly fetch the gameCIC, it's hard coded atm to 5(6105).
    Fixed but with selected rom title length. Not sure what happened but using strncpy now as well as the actual length of the string sent from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
    [internal_sd_card.c, mcu1.c, mcu2.c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]
2023-03-14 Added loading sprites to menu rom. Started breaking out for a animation framework.
2023-03-15 Added "reverse" text scrolling animation option. Made loading "text streams" use the reverse scrolling option so it looks like the "bits" are flowing into the cart sprite.
2023-03-23 Made a bunch of small changes. Menu rom has some good changes that should properly set the cic when it does simulate boot.
    The other changes to the firmware are more questionable and some should likely be reverted. I just need a checkpoint to continue debugging dma code.
    [internal_sd_card.c, mcu1.c, mcu2.c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]
2023-03-23 Streamlined the sram a bit more. Still doesn't write or load from sd card.
    [mcu1.c, n64_pi_task.c]
2023-03-25 Added a delay before loading box art in the menu rom. Helps it feel better when scrolling.
    This will compile and boot to menu rom. Bus timing is set to 0x2040, clocks are 336/4, although it likely doesn't need to run that fast.
    Eeprom save size is being fetched and sent to the mcu1. There seems to be an issue loading eeprom saves, though originally I thought it was because the file was in a sub folder. Not sure if there is a memory issue or what. Might only be able to have one file open at a time? Unsure but it requires more testing.
    [internal_sd_card.c, joybus.c, mcu1.c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]
2023-03-25 0x2040@220/2 Sanity checkin. mcu1 is currently printing. Serial is disabled.
2023-03-26 Will boot a loaded rom, not using flash atm. Checkin to show 300/4 running 0x1640 timings with 16bit dma. Have been unable to get 32bit dma to run fast enough.
2023-03-27 Use DMA for both psram and flash. Runninig bus patched to 0x2040 @ 266/4. Can likely get tighter timings if needed. Reenabled serial bridge.
    [mcu1.c, mcu2.c, n64_pi_task.c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]
2023-03-27 Added new register for rom metadata, cic/saveType. We are already extracting the info in the menu, just pass the values over to mcu2. Fixed eeprom loads... Can only have 1 file pointer at a time? I e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
    [internal_sd_card.c, joybus.c, mcu1.c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]
2023-03-28 Updated hardware files
    [board.kicad_sch, picocart64_v2.kicad_pcb, picocart64_v2.kicad_sch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]
2023-03-29 Dynamically allocate sram (can allocate 1Mbit this way) Save test still doesn't show up with 1Mbit support but did show 256kb and 768kb support.
    [internal_sd_card.c, mcu2.c, n64_pi_task.c]
2023-03-29 Moving some functions into debug.c as they aren't needed for running the actual cart and are more for testing various systems, currently the rom read/verify test.
2023-05-01 Updated schematic to include a chin for the USB port and slightly increased the length of the SD Card chin. This should help it be more accessible once inside a shell. Updated schematic to include pa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
    [board.kicad_sch, picocart64_v2.kicad_pcb, picocart64_v2.kicad_sch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]
2023-06-02 Kicad file change?
2023-07-10 Fixed issue with EEPROM saving, also optimized it to make saves to SD - only 30 seconds after load AND at least 1 second after a write has occured Moved the FIL object to global scope of internal_sd_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
    [internal_sd_card.c, joybus.c, mcu1.c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]
